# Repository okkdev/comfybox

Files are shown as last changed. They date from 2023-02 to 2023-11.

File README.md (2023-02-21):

# comfybox

A stickless fighting game controller, intended to be more ergonomic compared to the regular stickless style layout.

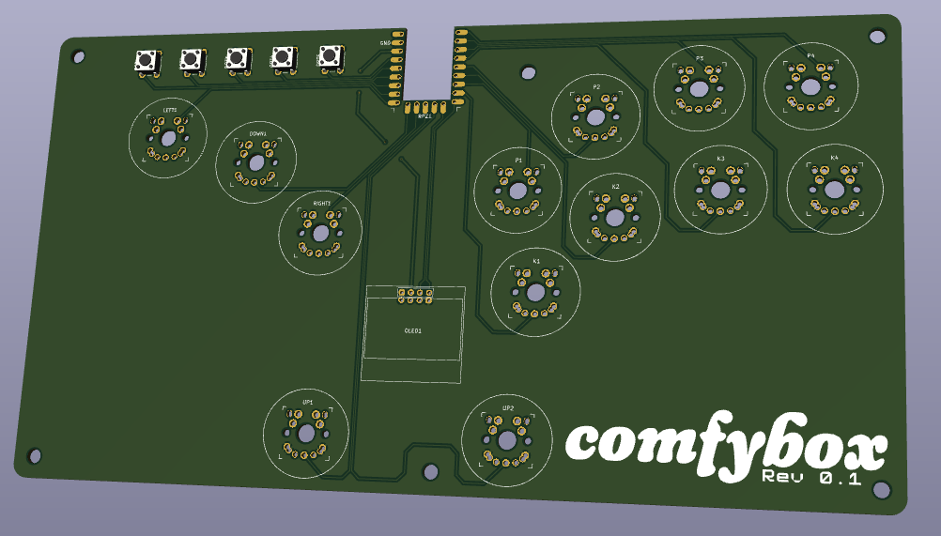
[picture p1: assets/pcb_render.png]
comfybox pcb


## Features

- Split and 16° angled buttons for improved ergonomics
- Compatible with Kailh Choc v1/v2, Gateron Low Profile 1.0/2.0 and regular MX
- Completely reversible PCB for southpaw layout
- OLED screen
- Powered by [GP2040-CE](https://github.com/OpenStickCommunity/GP2040-CE)
  - Button remapping
  - SOCD Modes
  - XInput, DirectInput and Nintendo Switch
  - Web UI

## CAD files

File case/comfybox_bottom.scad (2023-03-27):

$fn = 64;

//config
height = 8;
southpaw = false;

module rcube(width, depth, height, radius, center){
    points = [
        for (p = [
            [radius, radius],
            [radius, depth - radius],
            [width - radius, radius],
            [width - radius, depth - radius]
        ])
        if (center) [p[0] - width / 2, p[1] - depth / 2]
        else p
    ];
    hull(){
        for (p = points) translate(p) cylinder(r=radius, h=height);
    }
}

module case() {
    3_buttons = [
        [0,  0],
        [20.5, 20.5],
        [48,  28],
    ];
    4_buttons = [ each 3_buttons, [77,  28] ];

    right_buttons = [
        each 4_buttons,
        each [ for (b = 4_buttons) b + [6, -28] ],
        [0,  -67.5],
    ];
    left_buttons = [
        each [ for (b = 3_buttons) [-b[0], b[1]] ],
        [0,  -55.5],
    ];  
    
//    solder cutouts
    difference() {
    //    base
        rcube(350, 190, height, 15, center=true);
        
    //    pcb
        pcb_height = 1.6;
        translate([0, 29.60, height-pcb_height]) rcube(241, 131, 2, 4, center=true);

        buttons = [
            each [ for (b = left_buttons) b + [-35, 35] ],
            each [ for (b = right_buttons) b + [20, 47] ],
        ];
        
        for (b = buttons) translate([b[0], b[1], height-pcb_height-2]) cylinder(3, r=9);
        
//        opt buttons
        translate([-63, 85.5, height-pcb_height-2]) rcube(66, 12, 3, 6, center=true);
        
//        oled
        translate([-6.8, 17, height-pcb_height-2]) rcube(13, 6, 3, 3, center=true);
        
        mount_holes = [
    //        pcb
            [0, -29.5],
//            [-114, -29.5],
//            [114, -29.5],
            [114, 89],
            [-114, 89],
            [21.5, 80.5],
        
    //        case
            [165, 85],
            [165, -85],
            [-165, -85],
            [-165, 85],
        ];
        
        for (m = mount_holes) translate([m[0], m[1], -1]) cylinder(height+2, r=2);
    }
}
//                                           scale hack because of cnc
if (southpaw) mirror(v=[1,0,0]) case(); else scale([1.004, 1.004, 1]) case();

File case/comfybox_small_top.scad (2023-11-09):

$fa = 1;
$fs = 0.5;

//config
top = false;

module rsquare(size, radius, center) {
  x = size.x - radius * 2;
  y = size.y - radius * 2;
  offset(r = radius) square([ x, y ], center = center);
}

3_buttons = [
    [0,  0],
    [20.5, 20.5],
    [48,  28],
];
4_buttons = [ each 3_buttons, [77,  28] ];

right_buttons = [
    each 4_buttons,
    each [ for (b = 4_buttons) b + [6, -28] ],
    [0,  -67.5],
];
left_buttons = [
    each [ for (b = 3_buttons) [-b[0], b[1]] ],
    [0,  -55.5],
];

difference() {
//    base
    translate([0, 29.6, 0])
    rsquare([241, 131], 4, center=true);
    
    buttons = [
        each [ for (b = left_buttons) b + [-35, 35] ],
        each [ for (b = right_buttons) b + [20, 47] ],
    ];
    
    for (b = buttons) translate(b) circle(12);
        
    mount_holes = [
//        pcb
        [0, -29.5],
        [114, 89],
        [-114, 89],
        [21.5, 80.5],
//        bottom corners of pcb
        [-114, -29.5],
        [114, -29.5],
    ];
    
    for (m = mount_holes) translate(m) circle(2);
        
    if (top) {
        opt_buttons = [ for (i = [0:4]) [-34.5, 85.5] - [14*i, 0] ];
        for (o = opt_buttons) translate(o) circle(3.4);
    }
    else {
//        cutouts
//        opt buttons
        translate([-63, 85.5]) rsquare([66, 8], 2, center=true);
//        oled
        translate([-6.8, 5]) rsquare([28, 31], 2, center=true);
//        pico zero
        translate([-7, 83.1]) rsquare([22, 28], 2, center=true);
    }
}

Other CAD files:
case/comfybox_small_bottom.scad
case/comfybox_small_top_3d.scad
case/comfybox_top.scad
case/keycap.scad

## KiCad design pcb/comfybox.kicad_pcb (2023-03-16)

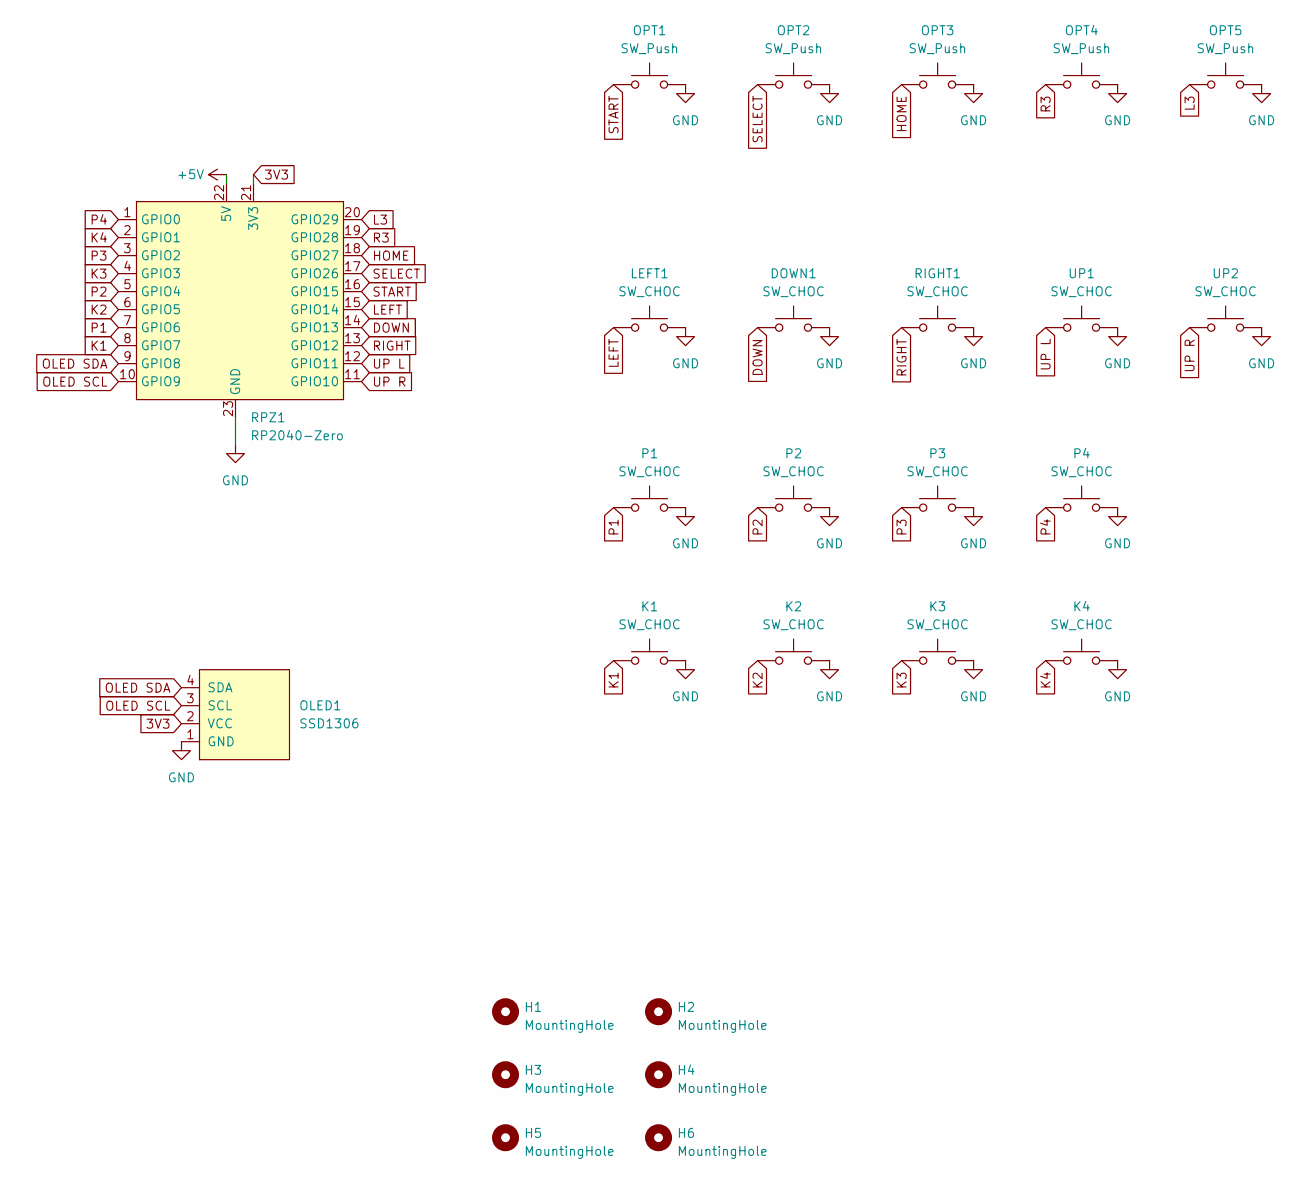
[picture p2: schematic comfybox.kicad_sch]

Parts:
DOWN1: SW_CHOC; Kailh_CPG1353_Gateron_KS33_MX_reversible
H1, H2, H3, H4, H5, H6: MountingHole; MountingHole_4mm
K1, K2, K3, K4: SW_CHOC; Kailh_CPG1353_Gateron_KS33_MX_reversible
LEFT1: SW_CHOC; Kailh_CPG1353_Gateron_KS33_MX_reversible
OLED1: SSD1306; SSD1306-128x64_OLED_reversible
OPT1, OPT2, OPT3, OPT4, OPT5: SW_Push; SW_PUSH_6mm
P1, P2, P3, P4: SW_CHOC; Kailh_CPG1353_Gateron_KS33_MX_reversible
RIGHT1: SW_CHOC; Kailh_CPG1353_Gateron_KS33_MX_reversible
RPZ1: RP2040-Zero; RP2040-Zero_reversible
UP1, UP2: SW_CHOC; Kailh_CPG1353_Gateron_KS33_MX_reversible

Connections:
3V3: OLED1.2 (VCC), RPZ1.21 (3V3)
+5V: RPZ1.22 (5V)
DOWN: DOWN1.1, RPZ1.14 (GPIO13)
GND: DOWN1.2, K1.2, K2.2, K3.2, K4.2, LEFT1.2, OLED1.1 (GND), OPT1.2, OPT2.2, OPT3.2, OPT4.2, OPT5.2, P1.2, P2.2, P3.2, P4.2, RIGHT1.2, RPZ1.23 (GND), UP1.2, UP2.2
HOME: OPT3.1, RPZ1.18 (GPIO27)
K1: K1.1, RPZ1.8 (GPIO7)
K2: K2.1, RPZ1.6 (GPIO5)
K3: K3.1, RPZ1.4 (GPIO3)
K4: K4.1, RPZ1.2 (GPIO1)
L3: OPT5.1, RPZ1.20 (GPIO29)
LEFT: LEFT1.1, RPZ1.15 (GPIO14)
OLED SCL: OLED1.3 (SCL), RPZ1.10 (GPIO9)
OLED SDA: OLED1.4 (SDA), RPZ1.9 (GPIO8)
P1: P1.1, RPZ1.7 (GPIO6)
P2: P2.1, RPZ1.5 (GPIO4)
P3: P3.1, RPZ1.3 (GPIO2)
P4: P4.1, RPZ1.1 (GPIO0)
R3: OPT4.1, RPZ1.19 (GPIO28)
RIGHT: RIGHT1.1, RPZ1.13 (GPIO12)
SELECT: OPT2.1, RPZ1.17 (GPIO26)
START: OPT1.1, RPZ1.16 (GPIO15)
UP L: RPZ1.12 (GPIO11), UP1.1
UP R: RPZ1.11 (GPIO10), UP2.1

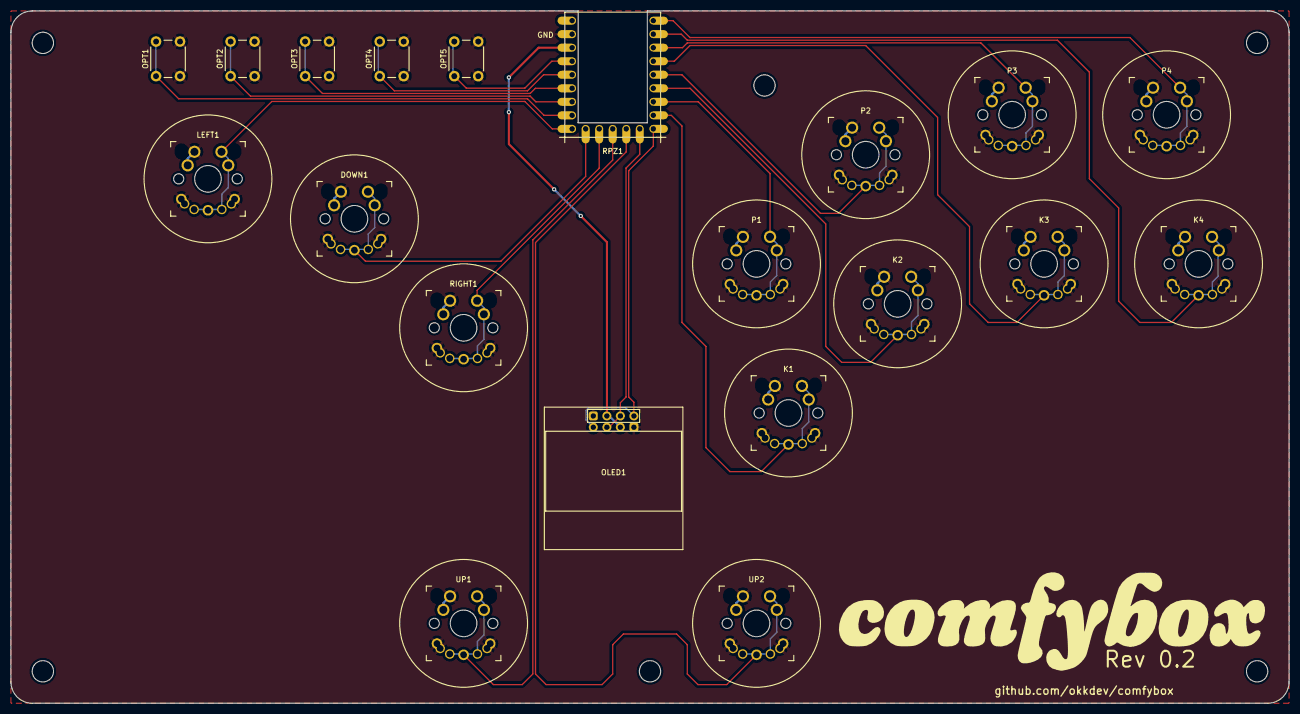
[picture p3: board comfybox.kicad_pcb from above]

Board: 2 copper layers, 240.0 x 130.0 mm, 28 parts (1 on the bottom side), 22 nets.

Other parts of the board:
LOGO: LOGO
LOGO#2: LOGO

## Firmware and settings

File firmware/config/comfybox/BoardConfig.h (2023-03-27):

/*
 * SPDX-License-Identifier: MIT
 * SPDX-FileCopyrightText: Copyright (c) 2021 Jason Skuby (mytechtoybox.com)
 */

#ifndef COMFYBOX_CONFIG_H_
#define COMFYBOX_CONFIG_H_

#include <GamepadEnums.h>
// This is the main pin definition section.
// This will let you specify which GPIO pin each button is assigned too.
// You can set any of the main pins as `-1` to disable it.
// The Turbo pin and LS + RS slider pins can also be set to `-1` to disable that
// functionality. Please note that only when `PIN_BUTTON_TURBO` is set to `-1`
// will the `T##` be removed from a connected display. Please note that only
// when `PIN_SLIDER_LS` and  `PIN_SLIDER_RS` are set to `-1` will the button
// combo shortcut for DP/LS/RS work. The buttons are listed in GP2040
// configuration, beside each the listed order is *GP2040 / Xinput / Switch /
// PS3 / Directinput / Arcade*

#define PIN_DPAD_UP 11        // UP
#define PIN_DPAD_DOWN 13      // DOWN
#define PIN_DPAD_RIGHT 12     // RIGHT
#define PIN_DPAD_LEFT 14      // LEFT
#define PIN_BUTTON_B1 7       // B1 / A / B / Cross / 2 / K1
#define PIN_BUTTON_B2 5       // B2 / B / A / Circle / 3 / K2
#define PIN_BUTTON_R2 3       // R2 / RT / ZR / R2 / 8 / K3
#define PIN_BUTTON_L2 1       // L2 / LT / ZL / L2 / 7 / K4
#define PIN_BUTTON_B3 6       // B3 / X / Y / Square / 1 / P1
#define PIN_BUTTON_B4 4       // B4 / Y / X / Triangle / 4 / P2
#define PIN_BUTTON_R1 2       // R1 / RB / R / R1 / 6 / P3
#define PIN_BUTTON_L1 0       // L1 / LB / L / L1 / 5 / P4
#define PIN_BUTTON_S1 26      // S1 / Back / Minus / Select / 9 / Coin
#define PIN_BUTTON_S2 15      // S2 / Start / Plus / Start / 10 / Start
#define PIN_BUTTON_L3 29      // L3 / LS / LS / L3 / 11 / LS
#define PIN_BUTTON_R3 28      // R3 / RS / RS / R3 / 12 / RS
#define PIN_BUTTON_A1 27      // A1 / Guide / Home / PS / 13 / ~
#define PIN_BUTTON_A2 -1      // A2 / ~ / Capture / ~ / 14 / ~
#define PIN_BUTTON_TURBO -1   // Turbo
#define PIN_BUTTON_REVERSE -1 // UDLR Reverse
#define PIN_SLIDER_LS -1      // Left Stick Slider
#define PIN_SLIDER_RS -1      // Right Stick Slider

// This is the SOCD section.
// SOCD stands for `simultaneous opposing cardinal directions`.
// There are three options for `DEFAULT_SOCD_MODE` currently:
// 1 - `SOCD_MODE_NEUTRAL` - This is a neutral SOCD.  EG. when you press `up` +
// `down` no input will be registered. 2 - `SOCD_MODE_UP_PRIORITY` - This is up
// priority SOCD.  EG. when you press `up` + `down` `up` will be registered. 3 -
// `SOCD_MODE_SECOND_INPUT_PRIORITY` - This is last priority SOCD.  EG. when you
// press and hold `up` then press `down` `down` will be registered.

#define DEFAULT_SOCD_MODE SOCD_MODE_UP_PRIORITY

// This is the LEDs section.
// The default `TURBO_LED_PIN` pin is set to `15` ( it is recommended to run
// through 3V3(OUT) with a resistor) The Turbo LED will flash at a speed
// consistant with the set speed of the Turbo when a Turbo button is active. It
// is recommended to disable the `TURBO_LED_PIN` by setting it to `-1` if you
// are sensitive of flashing lights. The default `BOARD_LEDS_PIN` pin is set to
// `28`. The board LED pin will allow you to connect addressible RGB LEDs on the
// Pico. Addressible RGB LEDs should be connected to the `VBUS` pin (#40), an
// avalible ground pin and the defined `BOARD_LEDS_PIN`. Special note - You
// should only ever use addressible RGB LEDs that are rated for 5v operation on
// the Pico. The defualt `LED_BRIGHTNESS_MAXIMUM` value is `50`. This will
// change how bright the LEDs are with `0` being off and `100` being full
// brightness. The minimum `LED_BRIGHTNESS_MAXIMUM` value is `0`. The maximum
// `LED_BRIGHTNESS_MAXIMUM` value is `100`. The defualt `LED_BRIGHTNESS_STEPS`
// value is `5`. This will change how many brightness steps there are when
// increasing or decreasing the brightness of the LEDs via the onboard shortcut.
// It is recommend to keep this value at `5` or `10`.
// The defualt `LED_FORMAT` is `LED_FORMAT_GRB`.
// You can also choose the `LED_FORMAT` of `LED_FORMAT_RGB` if your addressible
// RGB LEDs are not working as intended. The defualt `LEDS_PER_PIXEL` is set to
// `1`. This will change how many addressible RGB LEDs there are per button. The
// default LEDS_[BUTTON] is an order and has nothing to do with what GPIO pin
// something is connected to. Unless you are planning on running custom
// animations I would recommmend you leave this as is.

#define TURBO_ENABLED 0
#define TURBO_LED_PIN -1

#define BOARD_LEDS_PIN -1

#define LED_BRIGHTNESS_MAXIMUM 50
#define LED_BRIGHTNESS_STEPS 5
#define LED_FORMAT LED_FORMAT_GRB
#define LEDS_PER_PIXEL 1

#define LEDS_DPAD_LEFT 0
#define LEDS_DPAD_DOWN 1
#define LEDS_DPAD_RIGHT 2
#define LEDS_DPAD_UP 3
#define LEDS_BUTTON_B3 4
#define LEDS_BUTTON_B4 5
#define LEDS_BUTTON_R1 6
#define LEDS_BUTTON_L1 7
#define LEDS_BUTTON_B1 8
#define LEDS_BUTTON_B2 9
#define LEDS_BUTTON_R2 10
#define LEDS_BUTTON_L2 11
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

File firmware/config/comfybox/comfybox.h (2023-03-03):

/*
 * Copyright (c) 2020 Raspberry Pi (Trading) Ltd.
 *
 * SPDX-License-Identifier: BSD-3-Clause
 */

// -----------------------------------------------------
// NOTE: THIS HEADER IS ALSO INCLUDED BY ASSEMBLER SO
//       SHOULD ONLY CONSIST OF PREPROCESSOR DIRECTIVES
// -----------------------------------------------------

#ifndef _BOARDS_COMFYBOX_H
#define _BOARDS_COMFYBOX_H

// For board detection
#define COMFYBOX

// For crappy crystal
#ifndef PICO_XOSC_STARTUP_DELAY_MULTIPLIER
#define PICO_XOSC_STARTUP_DELAY_MULTIPLIER 64
#endif

// --- UART ---
#ifndef PICO_DEFAULT_UART
#define PICO_DEFAULT_UART 0
#endif
#ifndef PICO_DEFAULT_UART_TX_PIN
#define PICO_DEFAULT_UART_TX_PIN 0
#endif
#ifndef PICO_DEFAULT_UART_RX_PIN
#define PICO_DEFAULT_UART_RX_PIN 1
#endif

// --- LED ---
#ifndef PICO_DEFAULT_LED_PIN
#define PICO_DEFAULT_LED_PIN 25
#endif
// no PICO_DEFAULT_WS2812_PIN

// --- I2C ---
#ifndef PICO_DEFAULT_I2C
#define PICO_DEFAULT_I2C 0
#endif
#ifndef PICO_DEFAULT_I2C_SDA_PIN
#define PICO_DEFAULT_I2C_SDA_PIN 8
#endif
#ifndef PICO_DEFAULT_I2C_SCL_PIN
#define PICO_DEFAULT_I2C_SCL_PIN 9
#endif

// --- SPI ---
#ifndef PICO_DEFAULT_SPI
#define PICO_DEFAULT_SPI 0
#endif
#ifndef PICO_DEFAULT_SPI_SCK_PIN
#define PICO_DEFAULT_SPI_SCK_PIN 18
#endif
#ifndef PICO_DEFAULT_SPI_TX_PIN
#define PICO_DEFAULT_SPI_TX_PIN 19
#endif
#ifndef PICO_DEFAULT_SPI_RX_PIN
#define PICO_DEFAULT_SPI_RX_PIN 16
#endif
#ifndef PICO_DEFAULT_SPI_CSN_PIN
#define PICO_DEFAULT_SPI_CSN_PIN 17
#endif

// --- FLASH ---

#define PICO_BOOT_STAGE2_CHOOSE_W25Q080 1

#ifndef PICO_FLASH_SPI_CLKDIV
#define PICO_FLASH_SPI_CLKDIV 2
#endif

#ifndef PICO_FLASH_SIZE_BYTES
#define PICO_FLASH_SIZE_BYTES (2 * 1024 * 1024)
#endif

// Drive high to force power supply into PWM mode (lower ripple on 3V3 at light loads)
#define PICO_SMPS_MODE_PIN 23

#ifndef PICO_RP2040_B0_SUPPORTED
#define PICO_RP2040_B0_SUPPORTED 1
#endif

#endif

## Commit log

2023-02-08 basic schema
    [comfybox.kicad_pcb, comfybox.kicad_sch]
2023-02-08 fix option button schema
    [comfybox.kicad_sch]
2023-02-08 finished pcb without oled
    [comfybox.kicad_pcb, comfybox.kicad_sch]
2023-02-08 add oled
    [comfybox.kicad_pcb, comfybox.kicad_sch]
2023-02-09 adjust tracing
    [comfybox.kicad_pcb]
2023-02-09 improve spacing and redo tracing
    [comfybox.kicad_pcb, comfybox.kicad_sch]
2023-02-10 wip adjusted angle
    [comfybox.kicad_pcb]
2023-02-10 update libs and add KS33 support
    [comfybox.kicad_pcb, comfybox.kicad_sch]
2023-02-10 remove unused footprint
2023-02-11 layout experiments
    [comfybox.kicad_pcb]
2023-02-13 layout adjustments and MX compatibility
    [comfybox.kicad_pcb, comfybox.kicad_sch]
2023-02-13 add logo and update to kicad7
    [comfybox.kicad_pcb, comfybox.kicad_sch]
2023-02-13 redo traces
    [comfybox.kicad_pcb]
2023-02-13 remove reference
    [comfybox.kicad_pcb]
2023-02-14 add front ground plane
    [comfybox.kicad_pcb]
2023-02-14 add reversible footprints
2023-02-14 reversible rp2040
    [comfybox.kicad_pcb, comfybox.kicad_sch]
2023-02-14 add back oled
    [comfybox.kicad_pcb, comfybox.kicad_sch]
2023-02-14 add back silk screen
    [comfybox.kicad_pcb]
2023-02-14 rework reversibility
    [comfybox.kicad_pcb, comfybox.kicad_sch]
2023-02-16 add mounting holes
    [comfybox.kicad_pcb, comfybox.kicad_sch]
2023-02-21 update switch footprint
2023-02-21 update footprints
    [comfybox.kicad_pcb, comfybox.kicad_sch]
2023-02-21 add pcb render
2023-02-21 add pcb to readme
2023-02-23 add repo link
    [comfybox.kicad_pcb]
2023-02-23 add wip bottom case
    [comfybox_case.FCStd]
2023-02-24 lock all parts and add mounting holes
    [comfybox_case.FCStd]
2023-02-27 move case file
    [comfybox_bottom.FCStd, comfybox_case.FCStd]
2023-02-27 add top case
    [comfybox_top.scad]
2023-02-27 small adjustments
    [comfybox_bottom.FCStd, comfybox_top.scad]
2023-02-27 remade bottom in openscad
    [comfybox_bottom.scad]
2023-02-28 make bottom case configurable for southpaw layout
    [comfybox_bottom.scad]
2023-02-28 add inner layer config to top case
    [comfybox_bottom.scad, comfybox_top.scad]
2023-03-03 add wristrest to top case
    [comfybox_top.scad]
2023-03-03 add keycap model
    [keycap.scad]
2023-03-08 add more space to pcb cutout
    [comfybox_bottom.scad]
2023-03-08 fix corner radius and button size
    [comfybox_top.scad]
2023-03-08 adjust cap sizes
    [keycap.scad]
2023-03-08 remove old freescad case
    [comfybox_bottom.FCStd]
2023-03-08 update rp2040 footprint size
2023-03-08 update rp2040 footprint
    [comfybox.kicad_pcb]
2023-03-08 update oled silkscreen
    [comfybox.kicad_pcb]
2023-03-08 bump revision
    [comfybox.kicad_pcb, comfybox.kicad_sch]
2023-03-08 remove pad from choc v2 3rd pin
2023-03-09 adjust oled cutout size
    [comfybox_top.scad]
2023-03-16 adjust option button position
    [comfybox.kicad_pcb]
2023-03-16 case stuff...
    [comfybox_bottom.scad, comfybox_top.scad]
2023-03-27 wrist rests and adjustments
    [comfybox_bottom.scad, comfybox_top.scad, keycap.scad]
2023-03-28 adjust ali wrist rest size
    [comfybox_top.scad]
2023-04-24 update aliexpress wrist rests
    [comfybox_top.scad]
2023-11-09 add small case
    [comfybox_small_bottom.scad, comfybox_small_top.scad]
2023-11-09 update 3d case
    [comfybox_small_bottom.scad, comfybox_small_top.scad, comfybox_small_top_3d.scad]
2023-11-23 adjust top 3d
    [comfybox_small_top_3d.scad]
